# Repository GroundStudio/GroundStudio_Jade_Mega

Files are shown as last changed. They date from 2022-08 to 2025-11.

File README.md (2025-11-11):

GroundStudio Jade Mega
====================================
JJD2 (https://ardushop.ro/en/development-boards/1937-groundstudio-jade-m1-6427854029508.html)

Get it from [ardushop.ro](https://ardushop.ro/en/development-boards/1937-groundstudio-jade-m1-6427854029508.html)

Explore all the GroundStudio products at [ardushop.ro](https://ardushop.ro/en/37-groundstudio)

Description
-------------------
ATMEGA2560 based development board with 256kBytes of In-System Self-Programmable Flash program memory, 4kBytes EEPROM, 8kBytes Internal SRAM, 15 PWM Channels, 70 Digital Pins including 16 channel 10 bit ADC Pins and HT42B534 for USB comunication.

Contents
-------------------

* [/Documentation](https://github.com/GroundStudio/GroundStudio_Jade_Mega/tree/main/Documentation) -- Pinout.
* [/Hardware](https://github.com/GroundStudio/GroundStudio_Jade_Mega/tree/main/Hardware) -- Schematics, layout.

Versions
-------------------
*(Not all tags shown)*

- [REV 0.1]

License
-------------------

This is released under the [Attribution-ShareAlike 4.0 International (CC BY-SA 4.0)](https://creativecommons.org/licenses/by-sa/4.0/) license.
**You are welcome to use this for commercial purposes.**

Please consider contributing back to this project or others to help the open-source hardware community continue to thrive and grow!

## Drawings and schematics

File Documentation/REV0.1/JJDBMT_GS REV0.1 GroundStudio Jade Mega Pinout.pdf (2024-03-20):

# GroundStudio Jade MEGA

PA2

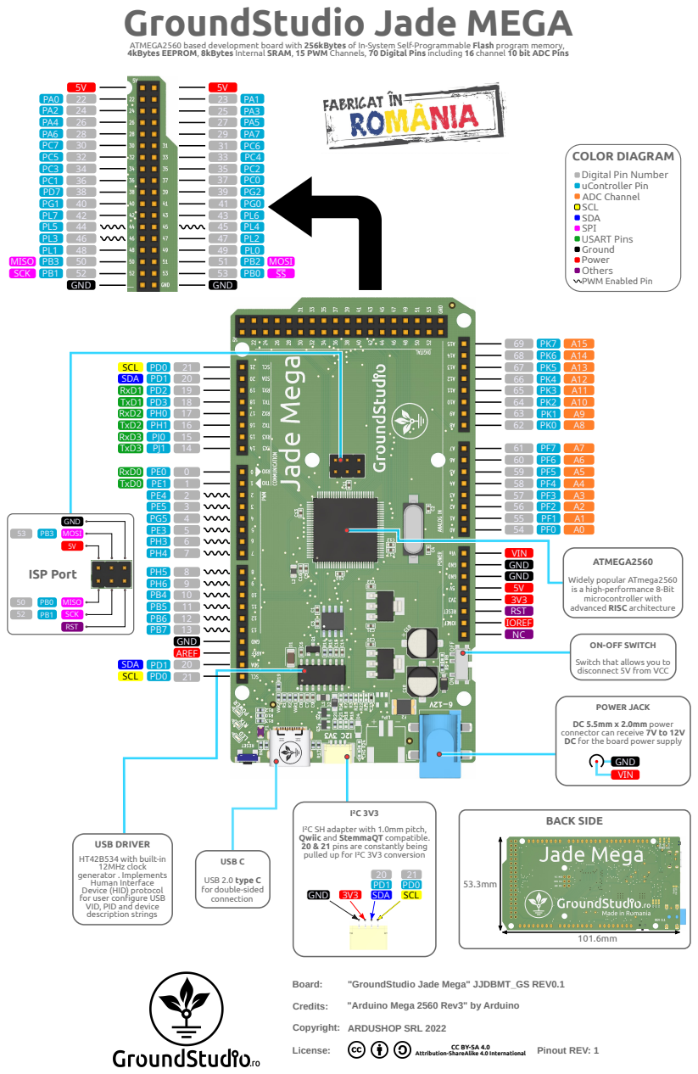
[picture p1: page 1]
Board:; Credits:; "Arduino Mega 2560 Rev3" by Arduino; Copyright:; License:; ARDUSHOP SRL 2022; Pinout REV: 1; ISP Port; GND MOSI 5V; PB1 SCK; MISO; RST; TxD0 PE1; RxD0 PE0; TxD1; RxD1; SCL; SDA; AREF; GND; VIN; IOREF; SCK; MOSI SS; TxD2; RxD2; TxD3; RxD3; SCL SDA; BACK SIDE; USB C; I²C 3V3; SDA SCL; GND 3V3; ATMEGA2560

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

COLOR DIAGRAM
Digital Pin Number
uController Pin
ADC Channel
SCL
SDA
SPI
USART Pins
Ground
Power
Others
PWM Enabled Pin

Widely popular ATmega2560
is a high-performance 8-Bit
microcontroller with
advanced RISC architecture

ON-OFF SWITCH
Switch that allows you to
disconnect 5V from VCC

POWER JACK
DC 5.5mm x 2.0mm power
connector can receive 7V to 12V
DC for the board power supply

I²C SH adapter with 1.0mm pitch,
Qwiic and StemmaQT compatible.
20 & 21 pins are constantly being
pulled up for I²C 3V3 conversion

USB DRIVER
HT42B534 with built-in
12MHz clock
generator . Implements Human Interface
Device (HID) protocol
for user configure USB VID, PID and device
description strings

USB 2.0 type C
for double-sided
connection

"GroundStudio Jade Mega" JJDBMT_GS REV0.1

Attribution-ShareAlike 4.0 International

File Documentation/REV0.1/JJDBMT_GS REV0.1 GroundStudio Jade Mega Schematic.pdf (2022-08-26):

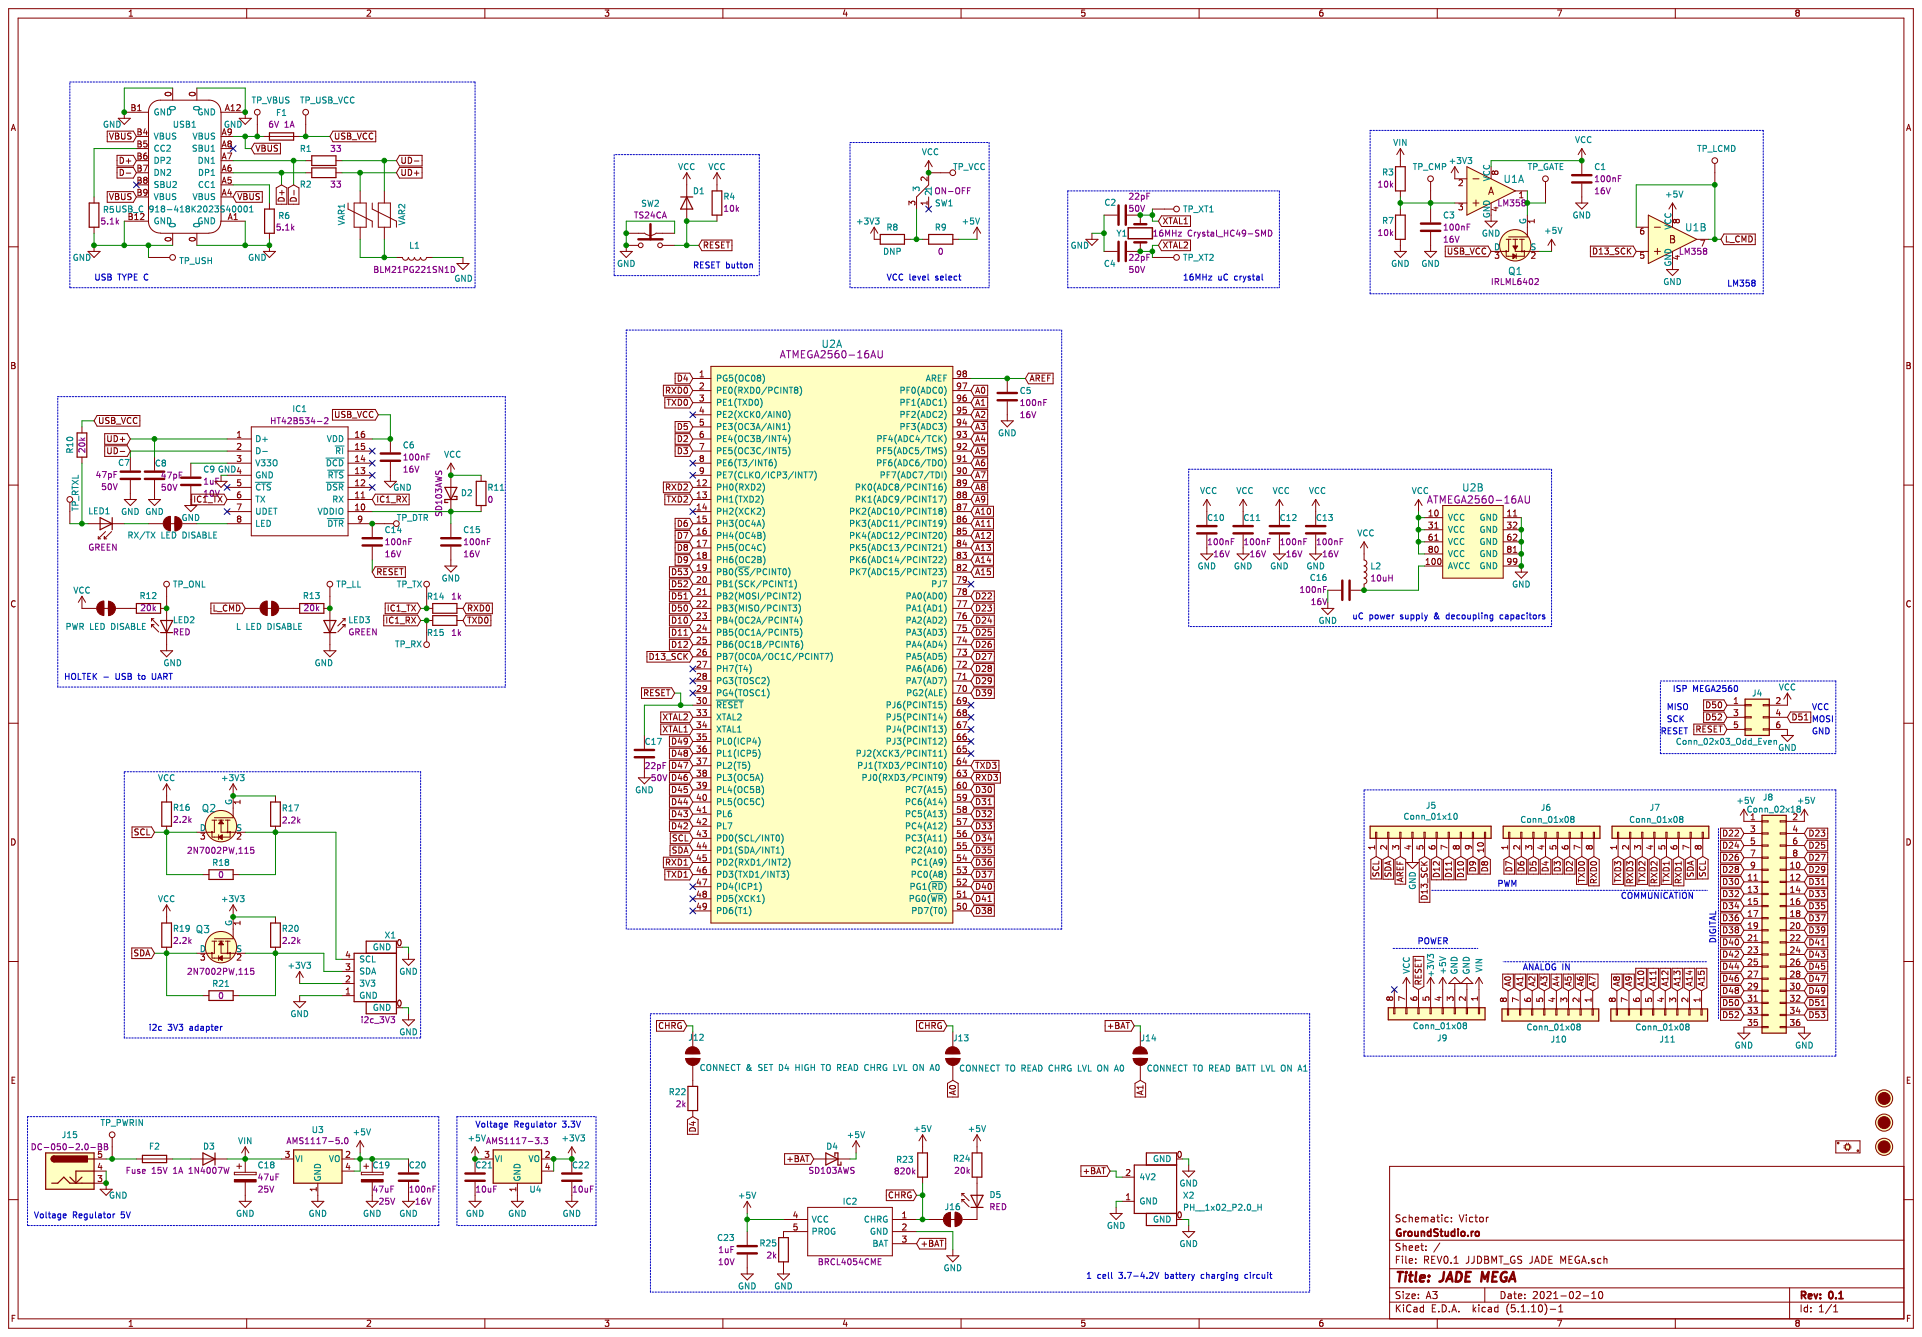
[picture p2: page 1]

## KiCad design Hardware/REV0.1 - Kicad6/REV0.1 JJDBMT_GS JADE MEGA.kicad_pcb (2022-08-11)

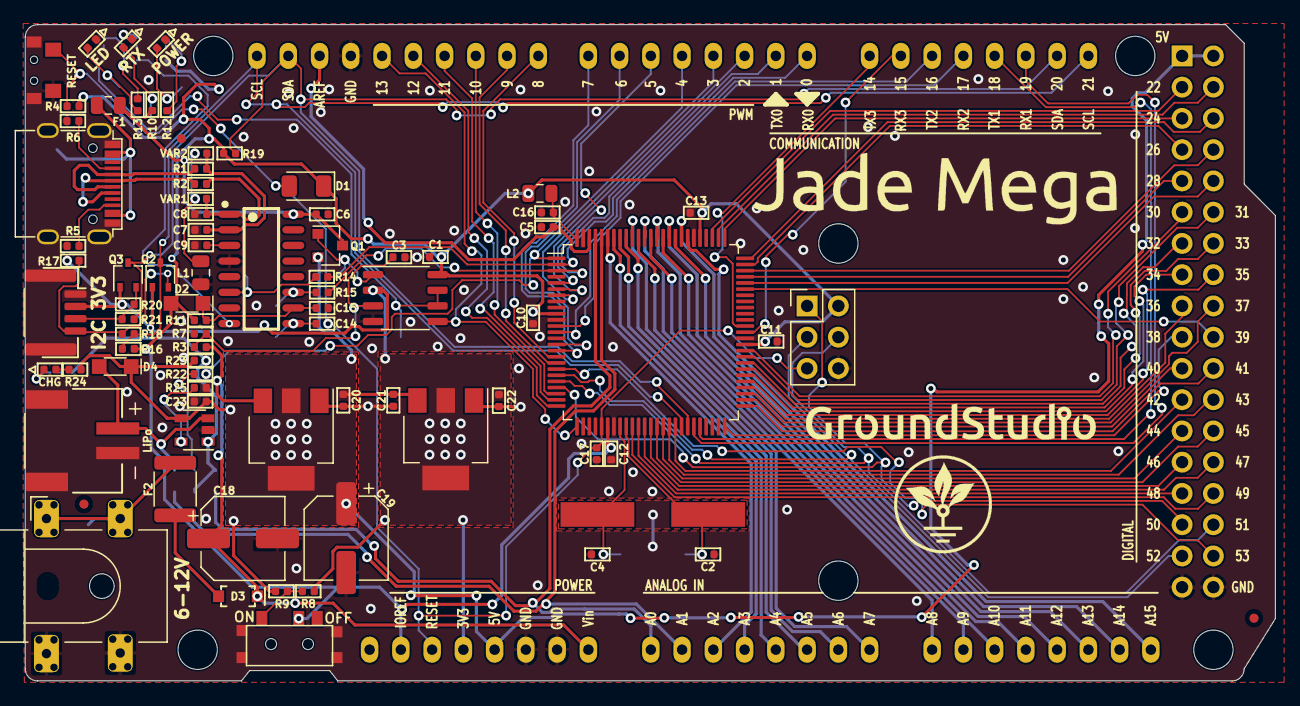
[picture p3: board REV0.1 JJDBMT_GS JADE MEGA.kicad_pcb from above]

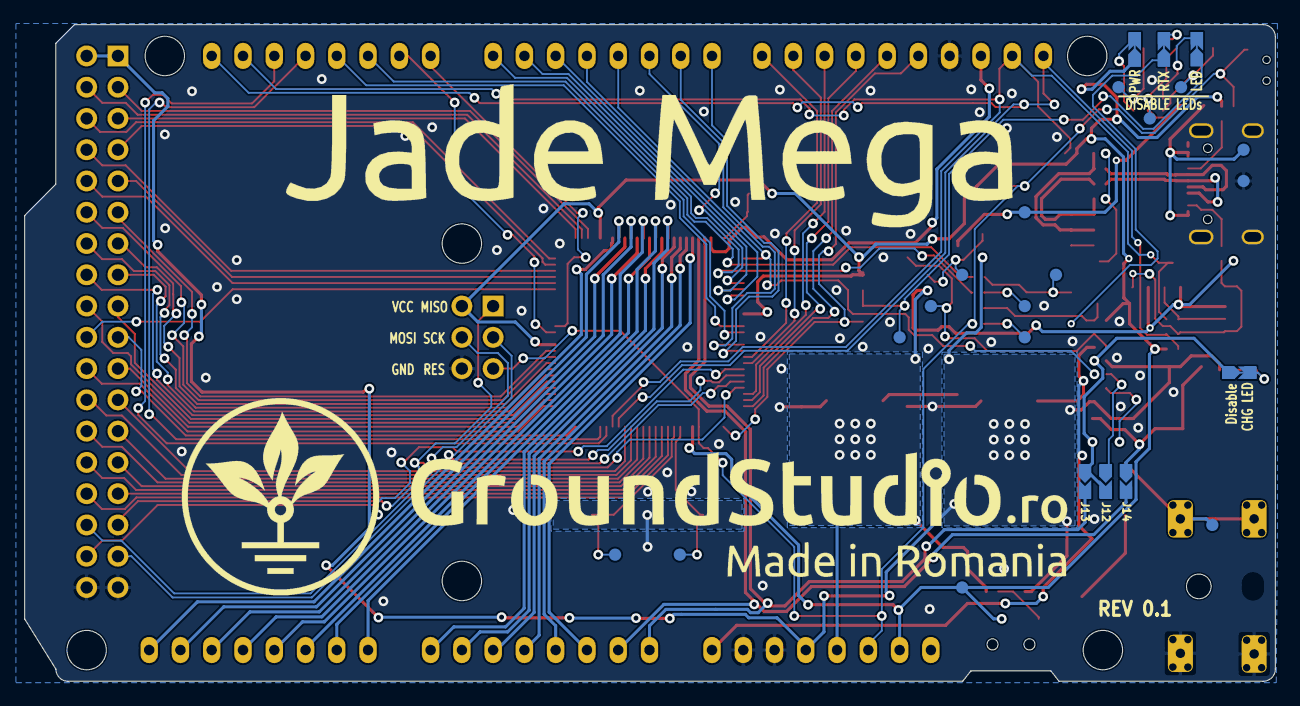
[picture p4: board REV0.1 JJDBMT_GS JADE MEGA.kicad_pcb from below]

Board: 2 copper layers, 101.6 x 53.3 mm, 112 parts (7 on the bottom side), 115 nets.

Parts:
C1, C3, C5, C6, C10, C11, C12, C13, C14, C15, C16, C20: C_0402_100nF_16V; C_0402_1005Metric
C2, C4, C17: C_0402_22pF_50V; C_0402_1005Metric
C7, C8: C_0402_47pF_50V; C_0402_1005Metric
C9, C23: C_0402_1uF_10V; C_0402_1005Metric
C18, C19: CP_Elec_6.3x5.4_47uF_25V; CP_Elec_6.3x5.4
C21, C22: C_0402_10uF_10V; C_0402_1005Metric
D1: D_1206_CD1206-S01575; D_1206_3216Metric
D2, D4: SOD-323 SD103AWS; SOD-323
D3: SOD-123 1N4007W; SOD-123
D5: LED_0402_RED; LED_0402_1005Metric
F1: Fuse_0805_MF-PSMF050X-2; Fuse_0805_2012Metric
F2: Fuse_1812_MF-MSMF050-2; Fuse_1812_4532Metric
FID1, FID2, FID3: Fiducial; Fiducial_0.75mm_Mask1.5mm
IC1: SOP-16_150MIL HT42B534-2; SOP-16_150MIL
IC2: SOT23-5 BRCL4054CME; SOT-23-5
J1: RX/TX LED DISABLE; SolderJumper_NC
J2: PWR LED DISABLE; SolderJumper_NC
J3: L LED DISABLE; SolderJumper_NC
J4: Conn_02x03_Odd_Even; PinHeader_2x03_P2.54mm_Vertical_Male
J5: Conn_01x10; PinHeader_1x10_P2.54mm_Vertical_Female
J6, J7, J9, J10, J11: Conn_01x08; PinHeader_1x08_P2.54mm_Vertical_Female
J8: Conn_02x18; PinHeader_2x18_P2.54mm_Vertical_Male
J12: CONNECT & SET D4 HIGH TO READ CHRG LVL ON A0; SolderJumper_NO
J13: CONNECT TO READ CHRG LVL ON A0; SolderJumper_NO
J14: CONNECT TO READ BATT LVL ON A1; SolderJumper_NO
J15: DC-005-5.5-Barr_Jck_SMD; DC-005-5.5-2.0MM-SMD
J16: SolderJumper_NC
L1: L_0805_BLM21PG221SN1D; L_0805_2012Metric
L2: L_0805_SCMI201209X100KT; L_0805_2012Metric
LED1, LED3: LED_0402_GREEN; LED_0402_1005Metric
LED2: LED_0402_RED; LED_0402_1005Metric
Q1: SOT-23 IRLML6402; SOT-23
Q2, Q3: SOT-323 2N7002PW; SOT-323_SC-70
R1, R2: R_0402_33; R_0402_1005Metric
R3, R4, R7: R_0402_10k; R_0402_1005Metric
R5, R6: R_0402_5.1k; R_0402_1005Metric
R8: DNP; R_0402_1005Metric
R9, R11, R18, R21: R_0402_0; R_0402_1005Metric
R10, R12, R13, R24: R_0402_20k; R_0402_1005Metric
R14, R15: R_0402_1k; R_0402_1005Metric
R16, R17, R19, R20: R_0402_2.2k; R_0402_1005Metric
R22, R25: R_0402_2k; R_0402_1005Metric
R23: R_0402_820k; R_0402_1005Metric
SW1: K3-1296S-E2
SW2: TS24CA
TP1: TP_VBUS; TestPoint
TP2: TP_USB_VCC; TestPoint
TP3: TP_LCMD; TestPoint
TP4: TP_VCC; TestPoint
TP5: TP_CMP; TestPoint
TP6: TP_GATE; TestPoint
TP7: TP_XT1; TestPoint
TP8: TP_USH; TestPoint
TP9: TP_XT2; TestPoint
TP10: TP_RTXL; TestPoint
TP11: TP_DTR; TestPoint
TP12: TP_ONL; TestPoint
TP13: TP_LL; TestPoint
TP14: TP_TX; TestPoint
TP15: TP_RX; TestPoint
TP16: TP_PWRIN; TestPoint
U1: SOP-8_3.9x4.9_P1.27 LM358; SOP-8_3.9x4.9mm_P1.27mm
U2: ATMEGA2560-16AU; TQFP-100_14x14mm_P0.5mm
U3: SOT-223 AMS1117-5.0; SOT-223
U4: SOT-223 AMS1117-3.3; SOT-223
USB1: USB_C 918-418K2023S40001; USB_C_C167321
VAR1, VAR2: R_0402_PS0402V014AT; R_0402_1005Metric
X1: SH_1x04_P1.0_H; SH__1x04_P1.00mm_Horizontal
X2: PH__1x02_P2.0_H; PH__1x02_P2.00mm_Horizontal
Y1: HC49-SMD 5M0-1600A2020; Crystal_HC49-SMD

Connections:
+3V3: C22.1, J9.5, Q2.1, Q3.1, R8.2, R17.1, R20.2, U1.2, U4.2, U4.4, X1.2
+5V: C19.1, C20.1, C21.1, C23.1, D4.1, IC2.4, J8.1, J8.2, J9.4, Q1.2, R9.1, R23.1, R24.2, U3.2, U3.4, U4.3
+BAT: D4.2, IC2.3, J14.1, X2.2
A0: J10.8, J13.2, U2.97
A1: J10.7, J14.2, U2.96
A2: J10.6, U2.95
A3: J10.5, U2.94
A4: J10.4, U2.93
A5: J10.3, U2.92
A6: J10.2, U2.91
A7: J10.1, U2.90
A8: J11.8, U2.89
A9: J11.7, U2.88
A10: J11.6, U2.87
A11: J11.5, U2.86
A12: J11.4, U2.85
A13: J11.3, U2.84
A14: J11.2, U2.83
A15: J11.1, U2.82
AREF: C5.1, J5.3, U2.98
CHRG: IC2.1, J12.2, J13.1, J16.1, R23.2
D2: J6.6, U2.6
D3: J6.5, U2.7
D4: J6.4, R22.1, U2.1
D5: J6.3, U2.5
D6: J6.2, U2.15
D7: J6.1, U2.16
D8: J5.10, U2.17
D9: J5.9, U2.18
D10: J5.8, U2.23
D11: J5.7, U2.24
D12: J5.6, U2.25
D13_SCK: J5.5, U1.5, U2.26
D22: J8.3, U2.78
D23: J8.4, U2.77
D24: J8.5, U2.76
D25: J8.6, U2.75
D26: J8.7, U2.74
D27: J8.8, U2.73
D28: J8.9, U2.72
D29: J8.10, U2.71
D30: J8.11, U2.60
D31: J8.12, U2.59
D32: J8.13, U2.58
D33: J8.14, U2.57
D34: J8.15, U2.56
D35: J8.16, U2.55
D36: J8.17, U2.54
D37: J8.18, U2.53
D38: J8.19, U2.50
D39: J8.20, U2.70
D40: J8.21, U2.52
D41: J8.22, U2.51
D42: J8.23, U2.42
D43: J8.24, U2.41
D44: J8.25, U2.40
D45: J8.26, U2.39
D46: J8.27, U2.38
D47: J8.28, U2.37
D48: J8.29, U2.36
D49: J8.30, U2.35
D50: J4.1, J8.31, U2.22
D51: J4.4, J8.32, U2.21
D52: J4.3, J8.33, U2.20
D53: J8.34, U2.19
D+: R2.2, USB1.A6, USB1.B6
D-: R1.2, USB1.A7, USB1.B7
GND: C1.2, C2.1, C3.2, C4.2, C5.2, C6.2, C7.1, C8.2, C9.2, C10.2, C11.2, C12.2, C13.2, C15.2, C16.1, C17.2, C18.2, C19.2, C20.2, C21.2, C22.2, C23.2, IC1.4, IC2.2, J4.6, J5.4, J8.35, J8.36, J9.2, J9.3, J15.3, J15.4, L1.1, LED2.1, LED3.1, R5.2, R6.2, R7.1, R25.1, SW2.1, SW2.2, SW2.3, TP8.~, U1.4, U2.11, U2.32, U2.62, U2.81, U2.99, U3.1, U4.1, USB1.0, USB1.A1, USB1.A12, USB1.B1, USB1.B12, X1.0, X1.1, X2.0, X2.1
IC1_RX: IC1.11, R15.2, TP15.~
IC1_TX: IC1.6, R14.2, TP14.~
L_CMD: J3.1, TP3.~, U1.6, U1.7
unnamed: C3.1, R3.1, R7.2, TP5.~, U1.3
unnamed: C9.1, IC1.3
unnamed: C14.1, IC1.9, TP11.~
unnamed: C15.1, D2.1, IC1.10, R11.2
unnamed: C16.2, L2.2, U2.100
unnamed: D3.2, F2.2
unnamed: D5.1, J16.2
unnamed: D5.2, R24.1
unnamed: F2.1, J15.5, TP16.~
unnamed: IC1.8, J1.1
unnamed: IC2.5, R25.2
unnamed: J1.2, LED1.1
unnamed: J2.2, R12.1
unnamed: J3.2, R13.1
unnamed: J12.1, R22.2
unnamed: L1.2, VAR1.2, VAR2.2
unnamed: LED1.2, R10.2, TP10.~
unnamed: LED2.2, R12.2, TP12.~
unnamed: LED3.2, R13.2, TP13.~
unnamed: Q1.1, TP6.~, U1.1
unnamed: Q2.2, R17.2, R18.1, X1.4
unnamed: Q3.2, R20.1, R21.1, X1.3
unnamed: R5.1, USB1.B5
unnamed: R6.1, USB1.A5
unnamed: R8.1, R9.2, SW1.3
RESET: C14.2, C17.1, D1.2, J4.5, J9.6, R4.1, SW2.4, U2.30
RXD0: J6.8, R14.1, U2.2
RXD1: J7.6, U2.45
RXD2: J7.4, U2.12
RXD3: J7.2, U2.63
SCL: J5.1, J7.8, Q2.3, R16.1, R18.2, U2.43
SDA: J5.2, J7.7, Q3.3, R19.1, R21.2, U2.44
TXD0: J6.7, R15.1, U2.3
TXD1: J7.5, U2.46
TXD2: J7.3, U2.13
TXD3: J7.1, U2.64
UD+: C8.1, IC1.1, R2.1, VAR1.1
UD-: C7.2, IC1.2, R1.1, VAR2.1
USB_VCC: C6.1, F1.1, IC1.16, Q1.3, R10.1, TP2.~
VBUS: F1.2, TP1.~, USB1.A4, USB1.A9, USB1.B4, USB1.B9
VCC: C1.1, C10.1, C11.1, C12.1, C13.1, D1.1, D2.2, J2.1, J4.2, J9.7, L2.1, R4.2, R11.1, R16.2, R19.2, SW1.2, TP4.~, U1.8, U2.10, U2.31, U2.61, U2.80
VIN: C18.1, D3.1, J9.1, R3.2, U3.3
XTAL1: C2.2, TP7.~, U2.34, Y1.1
XTAL2: C4.1, TP9.~, U2.33, Y1.2

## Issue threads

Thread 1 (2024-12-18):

GroundStudio Jade Mega won't connect with Arduino IDE_2.3.4

RDan3, 2024-12-18:
The above-mentioned board is not recognized by Arduino IDE_2.3.4.
First I get this message:
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
Then this one:
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
Nevertheless, the sketch (uploaded with Arduino IDE_1.8.19) runs properly, i.e. the LED13 blinks as expected.

However, it is recognized by Arduino IDE_1.8.19 and it works properly.

Solutions?

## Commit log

2022-08-11 - initial commit
    [REV0.1 JJDBMT_GS JADE MEGA.kicad_pcb, REV0.1 JJDBMT_GS JADE MEGA.kicad_sch]
2022-08-26 - added schematic pdf file
2022-08-26 - added "Kicad6" to revision folder name
    [REV0.1 JJDBMT_GS JADE MEGA.kicad_pcb, REV0.1 JJDBMT_GS JADE MEGA.kicad_sch]
2023-10-26 - added .step 3D file of the board
